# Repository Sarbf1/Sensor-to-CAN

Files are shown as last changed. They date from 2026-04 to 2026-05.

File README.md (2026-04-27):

# Sensor-to-CAN
A HAT for Arduino nano, to Connect nearly any sensor and send its walues using CAN or NMEA bus

This is an early version. The hardware is drwan, but not checked or tested.
The four layer board is slightly larger than the arduino nano R4, as i have added a shield ring (in case of use in high EMV areas such as in electric vehicles).

Also the code has not been written yet, but will follow.

The goal is to have a HAT board for on a Arduino Nano R4, that can connect to any sensor (3.3V 500mA, 5V 1A or Vin).
The sensor vaule (any voltage, or current input, selectable with a jumper) is processed by the arduino R4 and the sent using CANbus, using NMEA2000 protocol.
It has three LEDs that can be configured (currentls intended to show TX, RX and Erros) and two buttons, of wich one is used as Arduino Reset.

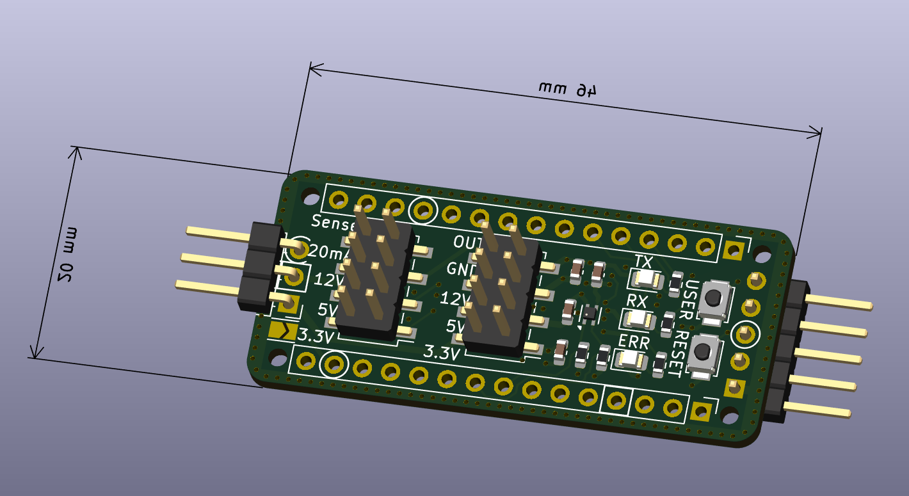
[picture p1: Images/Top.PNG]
front-view

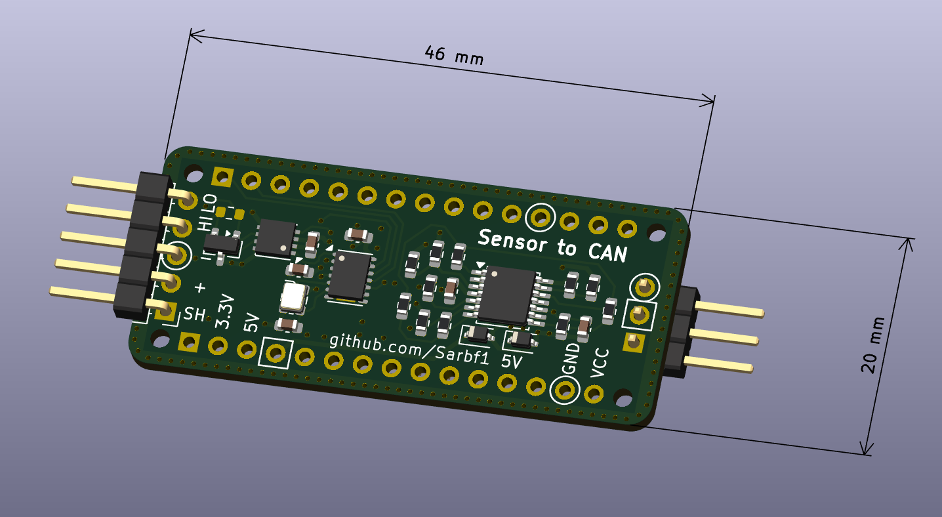
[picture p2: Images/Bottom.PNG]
back-view


## next steps
- [ ] build and test prototype
- [ ] Prgram Arduino R4
- [ ] implement CAN and NMEA200
- [ ] create Bill of material
- [ ] Make second physical prototype

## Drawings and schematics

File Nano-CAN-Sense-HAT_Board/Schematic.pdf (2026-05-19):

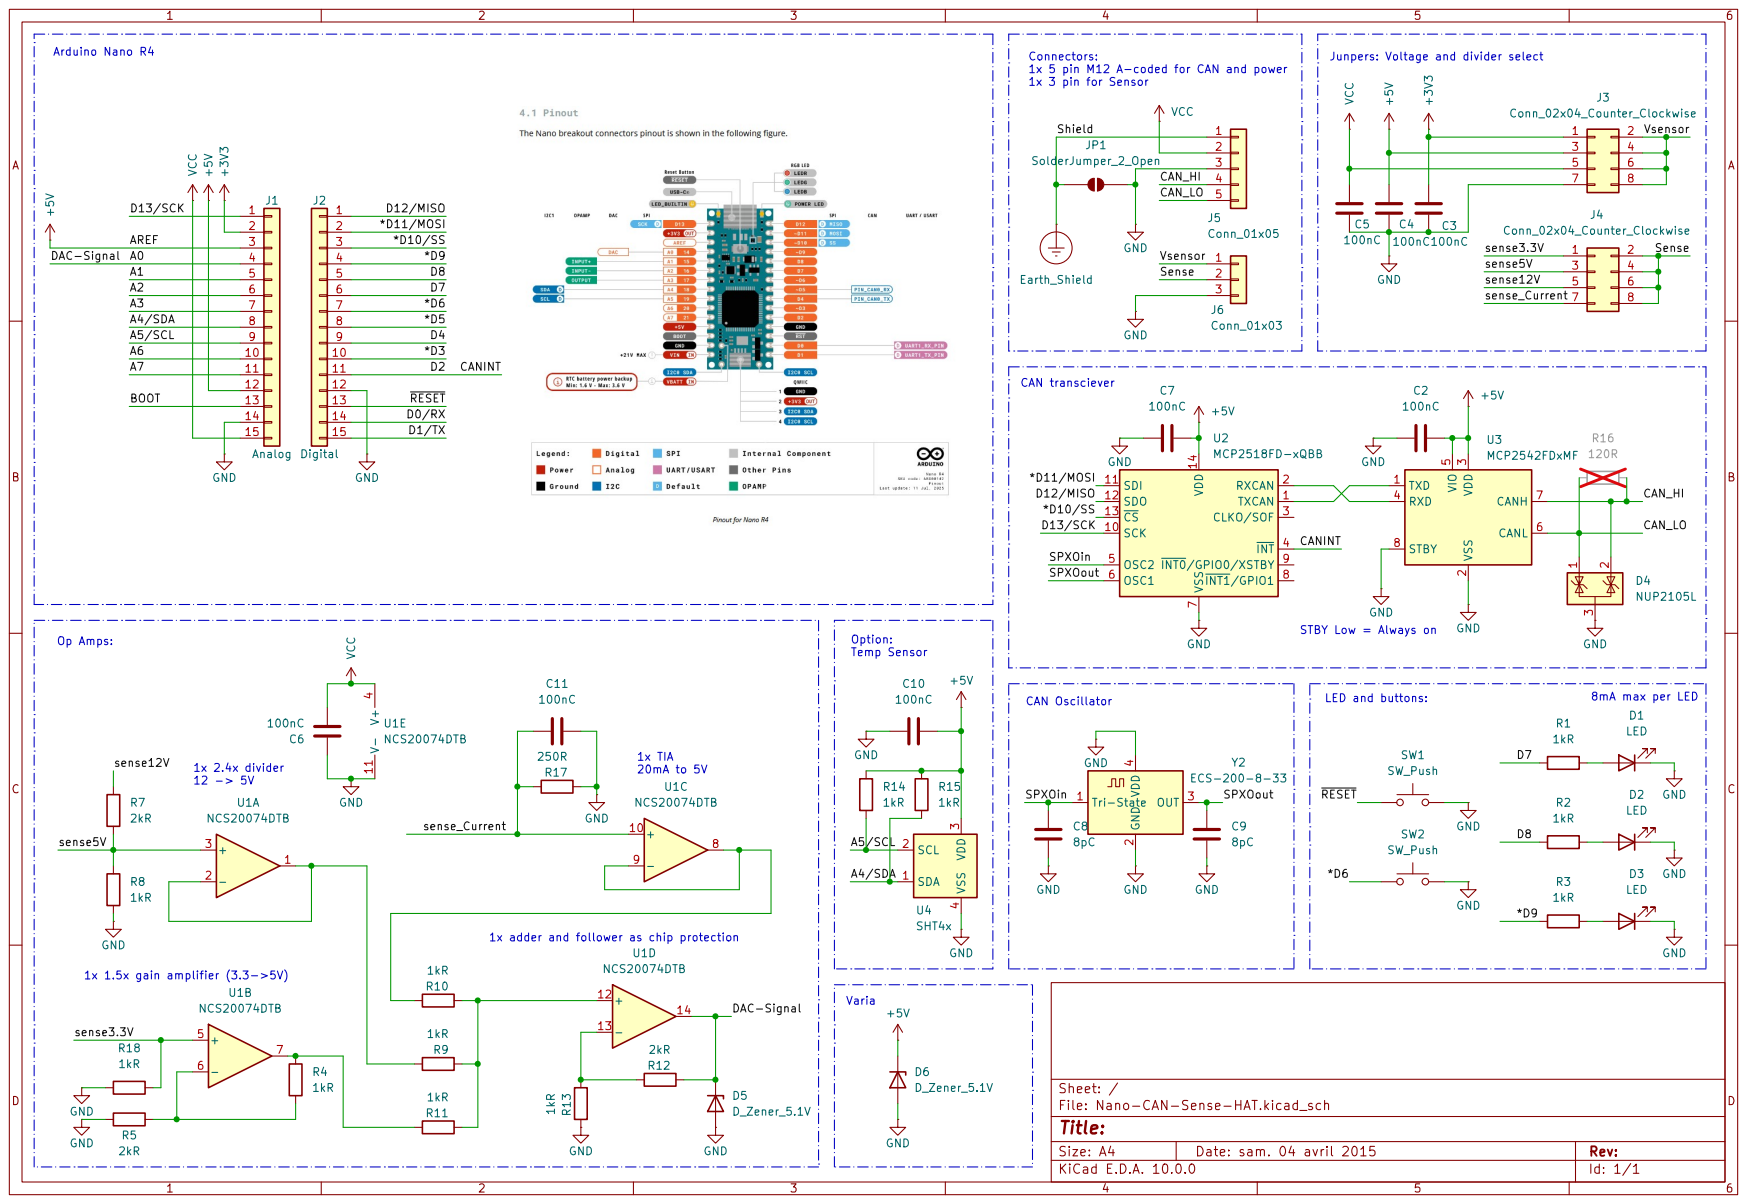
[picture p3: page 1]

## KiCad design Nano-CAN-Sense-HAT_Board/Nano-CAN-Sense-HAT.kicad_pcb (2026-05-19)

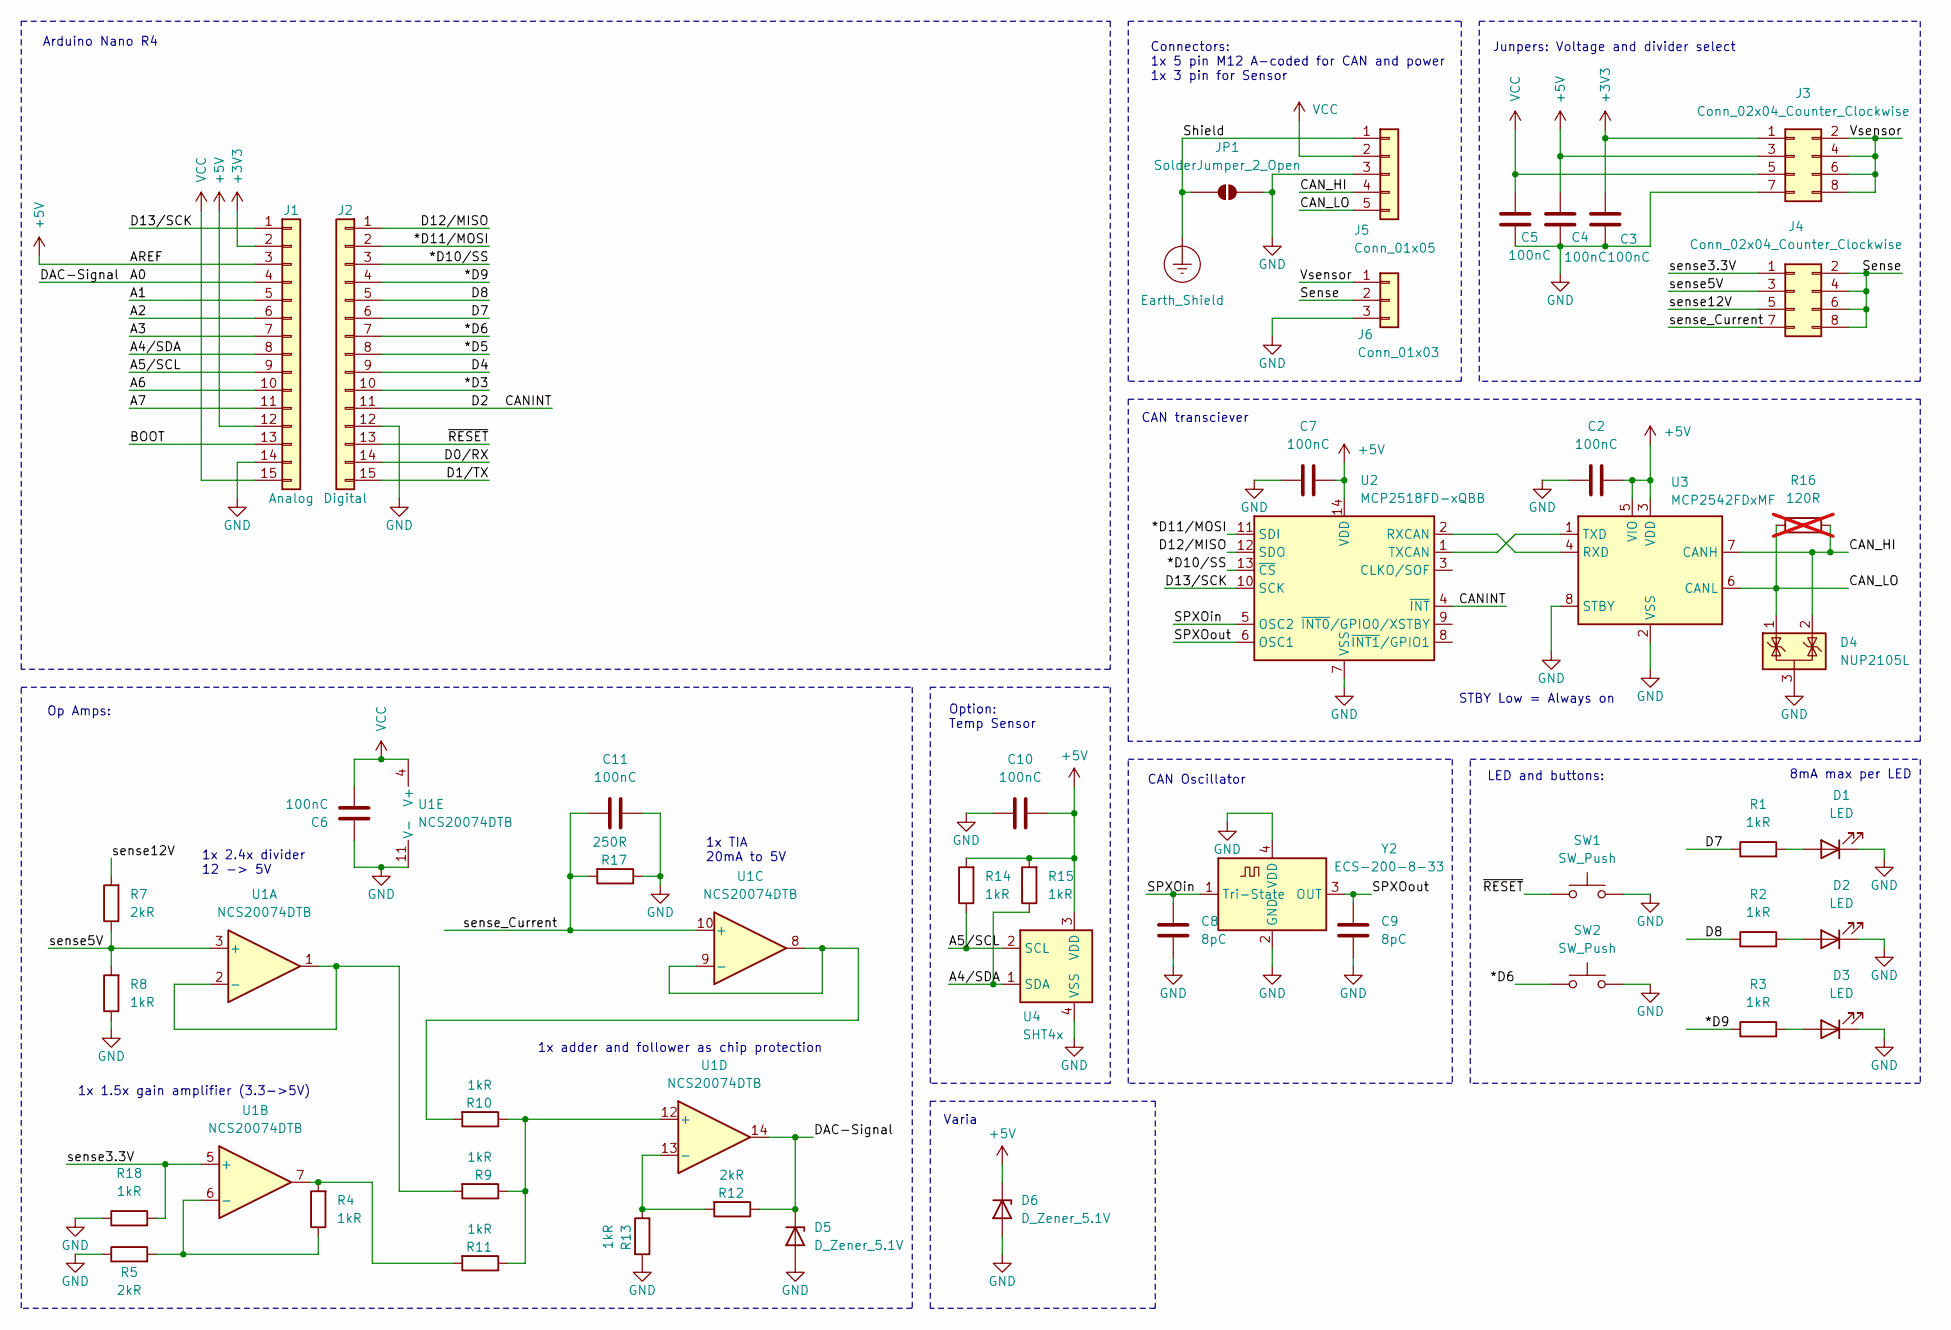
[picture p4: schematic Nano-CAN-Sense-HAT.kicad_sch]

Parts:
C2, C3, C4, C5, C6, C7, C10, C11: 100nC; C_0603_1608Metric
C8, C9: 8pC; C_0603_1608Metric
D1, D2, D3: LED; LED_0805_2012Metric
D4: NUP2105L; SOT-23
D5, D6: D_Zener_5.1V; D_SOD-323
J1: Analog; PinHeader_1x15_P2.54mm_Vertical
J2: Digital; PinHeader_1x15_P2.54mm_Vertical
J3, J4: Conn_02x04_Counter_Clockwise; PinHeader_2x04_P2.54mm_Vertical_SMD
J5: Conn_01x05; PinHeader_1x05_P2.54mm_Horizontal
J6: Conn_01x03; PinHeader_1x03_P2.54mm_Horizontal
JP1: SolderJumper_2_Open; SolderJumper-2_P1.3mm_Open_TrianglePad1.0x1.5mm
R1, R2, R3, R4, R8, R9, R10, R11, R13, R14, R15, R18: 1kR; R_0603_1608Metric
R5, R7, R12: 2kR; R_0603_1608Metric
R16: 120R; R_0603_1608Metric; not fitted
R17: 250R; R_0603_1608Metric
SW1, SW2: SW_Push; SW_SPST_B3U-1000P
U1: NCS20074DTB; TSSOP-14_4.4x5mm_P0.65mm
U2: MCP2518FD-xQBB; DFN-14-1EP_3x4.5mm_P0.65mm_EP1.65x4.25mm
U3: MCP2542FDxMF; DFN-8-1EP_3x3mm_P0.65mm_EP1.55x2.4mm
U4: SHT4x; Sensirion_DFN-4_1.5x1.5mm_P0.8mm_SHT4x_NoCentralPad
Y2: ECS-200-8-33; Oscillator_SMD_ECS_2520MV-xxx-xx-4Pin_2.5x2.0mm

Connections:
+3V3: C3.1, J1.2, J3.1
+5V: C2.2, C4.1, C7.2, C10.2, D6.1 (K), J1.3, J1.12, J3.3, R14.2, R15.2, U2.14 (VDD), U3.3 (VDD), U3.5 (VIO), U4.3 (VDD)
/*D3: J2.10
/*D5: J2.8
/*D6: J2.7, SW2.1
/*D9: J2.4, R3.1
/*D10/SS: J2.3, U2.13 (~CS)
/*D11/MOSI: J2.2, U2.11 (SDI)
/A0: D5.1 (K), J1.4, R12.1, U1.14
/A1: J1.5
/A2: J1.6
/A3: J1.7
/A4/SDA: J1.8, R15.1, U4.1 (SDA)
/A5/SCL: J1.9, R14.1, U4.2 (SCL)
/A6: J1.10
/A7: J1.11
/BOOT: J1.13
/CANINT: J2.11, U2.4 (~INT)
/CAN_HI: D4.2 (K), J5.4, R16.1, U3.7 (CANH)
/CAN_LO: D4.1 (K), J5.5, R16.2, U3.6 (CANL)
/D0/RX: J2.14
/D1/TX: J2.15
/D4: J2.9
/D7: J2.6, R1.1
/D8: J2.5, R2.1
/D12/MISO: J2.1, U2.12 (SDO)
/D13/SCK: J1.1, U2.10 (SCK)
/SPXOin: C8.2, U2.5 (OSC2), Y2.1 (Tri-State)
/SPXOout: C9.2, U2.6 (OSC1), Y2.3 (OUT)
/Sense: J4.2, J4.4, J4.6, J4.8, J6.2
/Vsensor: J3.2, J3.4, J3.6, J3.8, J6.1
/sense3.3V: J4.1, R18.2, U1.5 (+)
/sense5V: J4.3, R7.1, R8.2, U1.3 (+)
/sense12V: J4.5, R7.2
/sense_Current: C11.1, J4.7, R17.2, U1.10 (+)
/~RESET: J2.13, SW1.1
Earth_Shield: J5.1, JP1.1 (A)
GND: C2.1, C3.2, C4.2, C5.2, C6.2, C7.1, C8.1, C9.1, C10.1, C11.2, D1.1 (K), D2.1 (K), D3.1 (K), D4.3 (A), D5.2 (A), D6.2 (A), J1.14, J2.12, J3.7, J5.3, J6.3, JP1.2 (B), R5.1, R8.1, R13.2, R17.1, R18.1, SW1.2, SW2.2, U1.11 (V-), U2.7 (VSS), U2.15 (VSS), U3.2 (VSS), U3.8 (STBY), U3.9 (VSS), U4.4 (VSS), Y2.2 (GND), Y2.4 (VDD)
unnamed: D1.2 (A), R1.2
unnamed: D2.2 (A), R2.2
unnamed: D3.2 (A), R3.2
unnamed: R4.2, R11.2, U1.7
unnamed: R9.2, U1.1, U1.2 (-)
unnamed: R4.1, R5.2, U1.6 (-)
unnamed: R10.2, U1.8, U1.9 (-)
unnamed: R9.1, R10.1, R11.1, U1.12 (+)
unnamed: R12.2, R13.1, U1.13 (-)
unnamed: U2.2 (RXCAN), U3.4 (RXD)
unnamed: U2.1 (TXCAN), U3.1 (TXD)
VCC: C5.1, C6.1, J1.15, J3.5, J5.2, U1.4 (V+)

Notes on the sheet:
1x TIA 20mA to 5V
Junpers: Voltage and divider select
8mA max per LED
CAN Oscillator
Op Amps:
Arduino Nano R4
CAN transciever
1x 2.4x divider 12 -> 5V
Connectors: 1x 5 pin M12 A-coded for CAN and power 1x 3 pin for Sensor
STBY Low = Always on
LED and buttons:
1x adder and follower as chip protection
1x 1.5x gain amplifier (3.3->5V)
Varia
Option: Temp Sensor

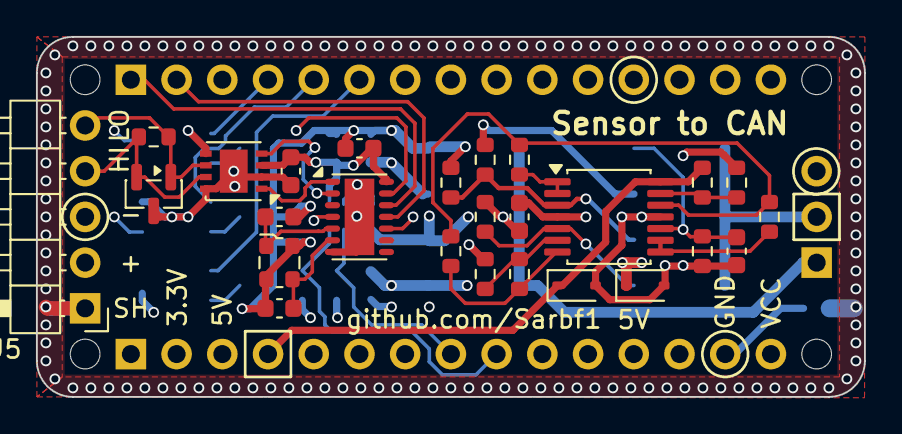
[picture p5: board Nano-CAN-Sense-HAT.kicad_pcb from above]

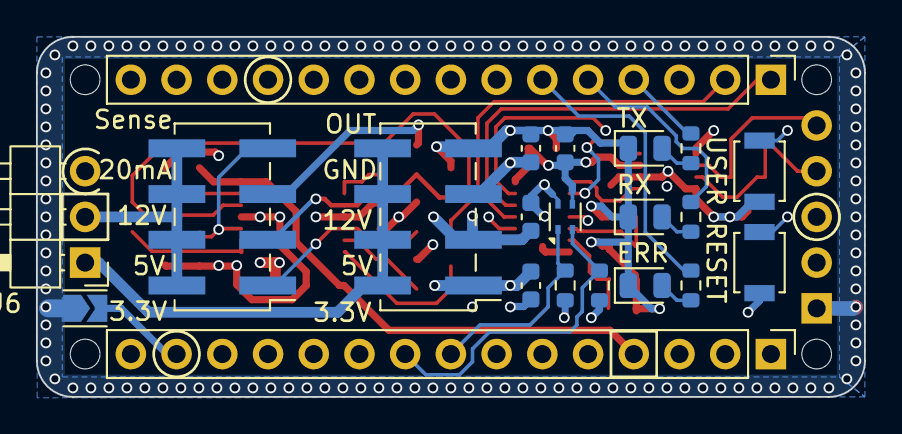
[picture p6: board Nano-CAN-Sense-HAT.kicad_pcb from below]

Board: 4 copper layers, 46.0 x 20.0 mm, 51 parts (21 on the bottom side), 39 nets.

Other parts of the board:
MH1, MH2, MH3, MH4: MountingHole_65mil

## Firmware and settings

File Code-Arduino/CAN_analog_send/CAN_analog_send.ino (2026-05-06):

// CAN Send Example
//

#include <mcp_can.h>
#include <SPI.h>

MCP_CAN CAN0(10);     // Set CS to pin 10
#define CAN0_INT 2    // Set INT to pin 2

int sensorPin = 14;   // select the input pin for the potentiometer
int sensorValue = 0;  // variable to store the value coming from the sensor

void setup()
{
  Serial.begin(115200);

  // Initialize MCP2515 running at 16MHz with a baudrate of 500kb/s and the masks and filters disabled.
  if(CAN0.begin(MCP_ANY, CAN_500KBPS, MCP_16MHZ) == CAN_OK) Serial.println("MCP2515 Initialized Successfully!");
  else Serial.println("Error Initializing MCP2515...");

  CAN0.setMode(MCP_NORMAL);   // Change to normal mode to allow messages to be transmitted
}

byte data[8] = {0x00, 0x01, 0x02, 0x03, 0x04, 0x05, 0x06, 0x07};

void loop()
{

    // read the value from the sensor:
  sensorValue = analogRead(sensorPin);

  data[7] = sensorValue;


  // send data:  ID = 0x100, Standard CAN Frame, Data length = 8 bytes, 'data' = array of data bytes to send
  byte sndStat = CAN0.sendMsgBuf(0x100, 0, 8, data);
  if(sndStat == CAN_OK){
    Serial.println("Message Sent Successfully!");
  } else {
    Serial.println("Error Sending Message...");
  }
  delay(100);   // send data per 100ms
}

/*********************************************************************************************************
  END FILE
*********************************************************************************************************/

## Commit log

2026-04-18 Improved Can for CAN-FD
    [Nano-CAN-Sense-HAT.kicad_pcb, Nano-CAN-Sense-HAT.kicad_sch]
2026-04-19 Added images, and Readme
    [Nano-CAN-Sense-HAT.kicad_pcb]
2026-04-19 Added Temp sensor SHT4x, rounded board edge
    [Nano-CAN-Sense-HAT.kicad_pcb, Nano-CAN-Sense-HAT.kicad_sch]
2026-04-19 added Schematic as PDF for quick inspection without Kicad
2026-04-19 Changed oscillator, improved GND layout
    [Nano-CAN-Sense-HAT.kicad_pcb, Nano-CAN-Sense-HAT.kicad_sch]
2026-04-21 Added BOM, defined footprints
    [Nano-CAN-Sense-HAT.kicad_pcb, Nano-CAN-Sense-HAT.kicad_sch]
2026-04-23 Rodone all rounting, changed to 4-layer baord
    [Nano-CAN-Sense-HAT.kicad_pcb, Nano-CAN-Sense-HAT.kicad_sch]
2026-04-27 Minor board changes, cosmetics, new pictures
    [Nano-CAN-Sense-HAT.kicad_pcb]
2026-04-28 power distribution using copper pours Gitignore *.zip
    [Nano-CAN-Sense-HAT.kicad_pcb]
2026-04-29 aestethics, improved lables
    [Nano-CAN-Sense-HAT.kicad_pcb]
2026-05-06 Started draft coding Layout fixes
    [Nano-CAN-Sense-HAT.kicad_pcb, Nano-CAN-Sense-HAT.kicad_sch]
2026-05-14 Changed OpAmp, improved lables
    [Nano-CAN-Sense-HAT.kicad_pcb, Nano-CAN-Sense-HAT.kicad_sch]
2026-05-17 Opamp supply 12V, Added Zener for protection
    [Nano-CAN-Sense-HAT.kicad_pcb, Nano-CAN-Sense-HAT.kicad_sch]
2026-05-19 Improved lables, better 5V protection diode, new images
    [Nano-CAN-Sense-HAT.kicad_pcb, Nano-CAN-Sense-HAT.kicad_sch]
